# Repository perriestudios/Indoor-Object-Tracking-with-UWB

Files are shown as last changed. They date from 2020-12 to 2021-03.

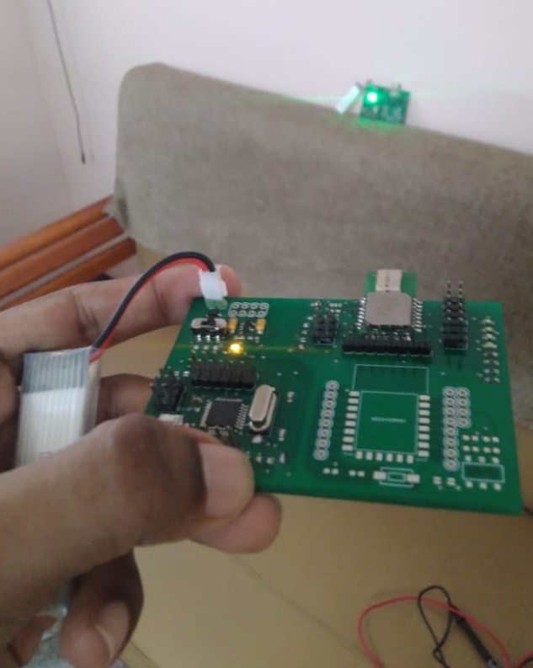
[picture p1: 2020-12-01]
Project Pictures/image15.jpeg

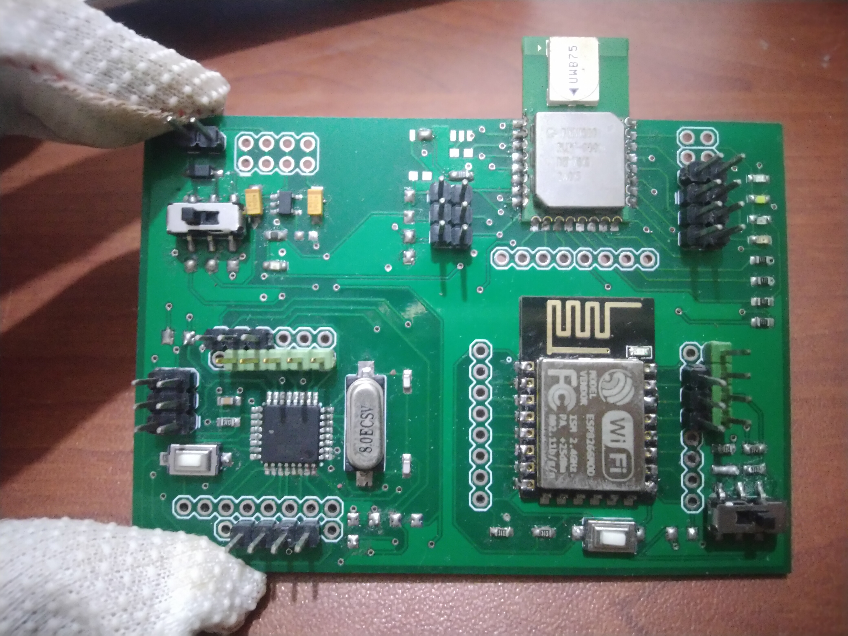
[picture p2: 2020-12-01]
Project Pictures/IMG_20201201_192204.jpg

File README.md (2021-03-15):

# <p align="center">Indoor-Object-Tracking-using-UWB </p>
## Introduction

<p align= "justify" > The objective of this project was to create an accurate general-purpose indoor localization system. Ultra-wideband(UWB) a wireless radio technology was chosen to achieve this. UWB offers high accuracy of localization, low latency, minimal interference and noise, and large bandwidth. DW1000 is an RF TX/RX IC manufactured by Decawave for UWB applications. This project uses the DW1000 IC in the form factor of module DWM1000. The hardware for the project was designed around this module with a few preferable features like access to the internet using an ESP8266-12E and programming support using the Arduino IDE. The system uses the Two-Way Ranging(TWR) technique for localization. The position computing is done by trilateration on the tag which is coupled with the object being tracked. A localization accuracy of about 12cm was achieved in a room of size 3x3m.</p>

## System Design

<p align="center">
  
</p>
<p align= "justify" > In order to track an object, a device addressed "Tag" is attached to it. Devices callled "Anchors" are placed around the indoor environment to provide a spatial reference for the tag. Before the system starts tracking, the anchors should be fixed at different locations in the room and their coordinates are programmed in the tag. As shown in the above block diagram, the anchors are placed at (x1,y1),(x2,y2) and (x3,y3) respectively. Calibration of the DWM1000 is then done to accomodate for the slight difference in the radiation pattern of each antenna as mentioned in the datasheet of the module.</p>

## Working

<p align= "justify" > Once the setup is ready, the tag performs Two-Way Ranging to determine its distance from each anchor. The three distances are then substituted into the trilateration formula to determine the exact position. This data may then be shared with an anchor with a Wi-Fi module called the master anchor. The master anchor can then update the data anywhere over the internet. In this project, a dynamic webpage hosted on the ESP8266 displays the coordinates of the object. This entire cycle is repeated to track the position of the tag(in turn the object) in real time. A flow chart of the process is shown below:</p>


## Hardware
### PCB: Version 1

<p align= "justify" > As stated in the introduction, the hardware was designed around the DWM1000 module. Since the module operates between 2.8-3.6v, the system voltage was fixed to be 3v3. This also provided the convinience of using a handy single cell 750mah lipo battery. ATmega328P was chosen as the microcontroller due to my familiarity with it. An external 8MHz crystal oscillator was connected to ensure the microcontroller is clocked at the fastest possible speed at 3v3. The minimal circuit required for ESP8266 was designed and interfaced with the ATmega328P over the I2C bus while the DWM1000 uses SPI. IC MIC5219 a low cost 500mA LDO was used to regulate the supply voltage to 3v3 from the battery. Additionally, reverse polarity protection using a diode is added. Switches were provided to control power and reset of ATmega328P and ESP8266, while LED's were provided to indicate the status of power and DWM1000.</p>



<p align= "justify" > The above PCB was designed in Autodesk Eagle. The design files can be found in the folder Master_V1 under the Hardware section of this repository. </p>

### PCB: Version 2

<p align= "justify" > The major feature of version 2 addition of programming over the USB. In the previous version, the bootloader was initally burned using an ATMEL ICE debugger and the program written over UART using an Arduino Uno performing USB-TTL conversion. However, I found it very inconvienient to interconnect the Uno everytime, reset it during programming and reading the data serially. Hence, the popular USB-TTL converter CH340G was added to support quicker programming and access to serial monitor. Pads were placed on the bottom to burn the bootloader using pogo pins. I also reduced the size of the crystals and switches to achieve the smallest possible form factor. </p>

<p align="center">

</p>

<p align= "justify" > The design files can be found under the Tag_V2 and Anchor_V2 folders respectively. The anchor design contains an additional ESP8266 placed in the bottom. </p>

### Enclosure

<p align="center">

</p>

<p align= "justify" > An enclosure was designed to house the device in Autodesk Fusion 360. The base was intended to be 3d printed on a PLA base which the lid will be a transparent laser cut acrylic. The PCB will be screwed on to the enclosure. The design file can be found under the hardware section</p>

## Software

<p align= "justify" > The firmware for the project was completely written in Arduino IDE with <a href="https://github.com/thotro/arduino-dw1000" target="_blank" rel="noopener noreferrer">arduino-dw1000 library</a> developed by Thomas Trojer. The programs could be found under the software section of this repository. </p>

## Working

<p align= "justify" > After uploading the program, the tag should be set in calibration mode to perform TWR and correct the calibration constant. After this, open a browser and navigate to the IP addess mentioned in the serial monitor of the master-anchor. The position of the tag will be updated every 10s in real-time with an accuracy < 30cm.</p>



## Outcome

<p align= "justify" >This capstone project was undertaken as part of my UG curriculum. Version 2 of the hardware did not progress beyond the design stage due to my graduation in May 2020, during the middle of the pandemic here. Fortunately, I was able to demonstate the working of the system using the first version of the hardware to earn my degree. However, as a hobby project, I am working on a TDoA implementation of the system to be deployed at Beeclust MRSL for tracking robots. It will be replacement for the april tags currently used in the projects. There are certain aspects of the system that could still be improved. Feel free to contact me if you would like to improve this project.</p>

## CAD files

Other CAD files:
Hardware/Enclosure_V2/Tag_v2.f3d

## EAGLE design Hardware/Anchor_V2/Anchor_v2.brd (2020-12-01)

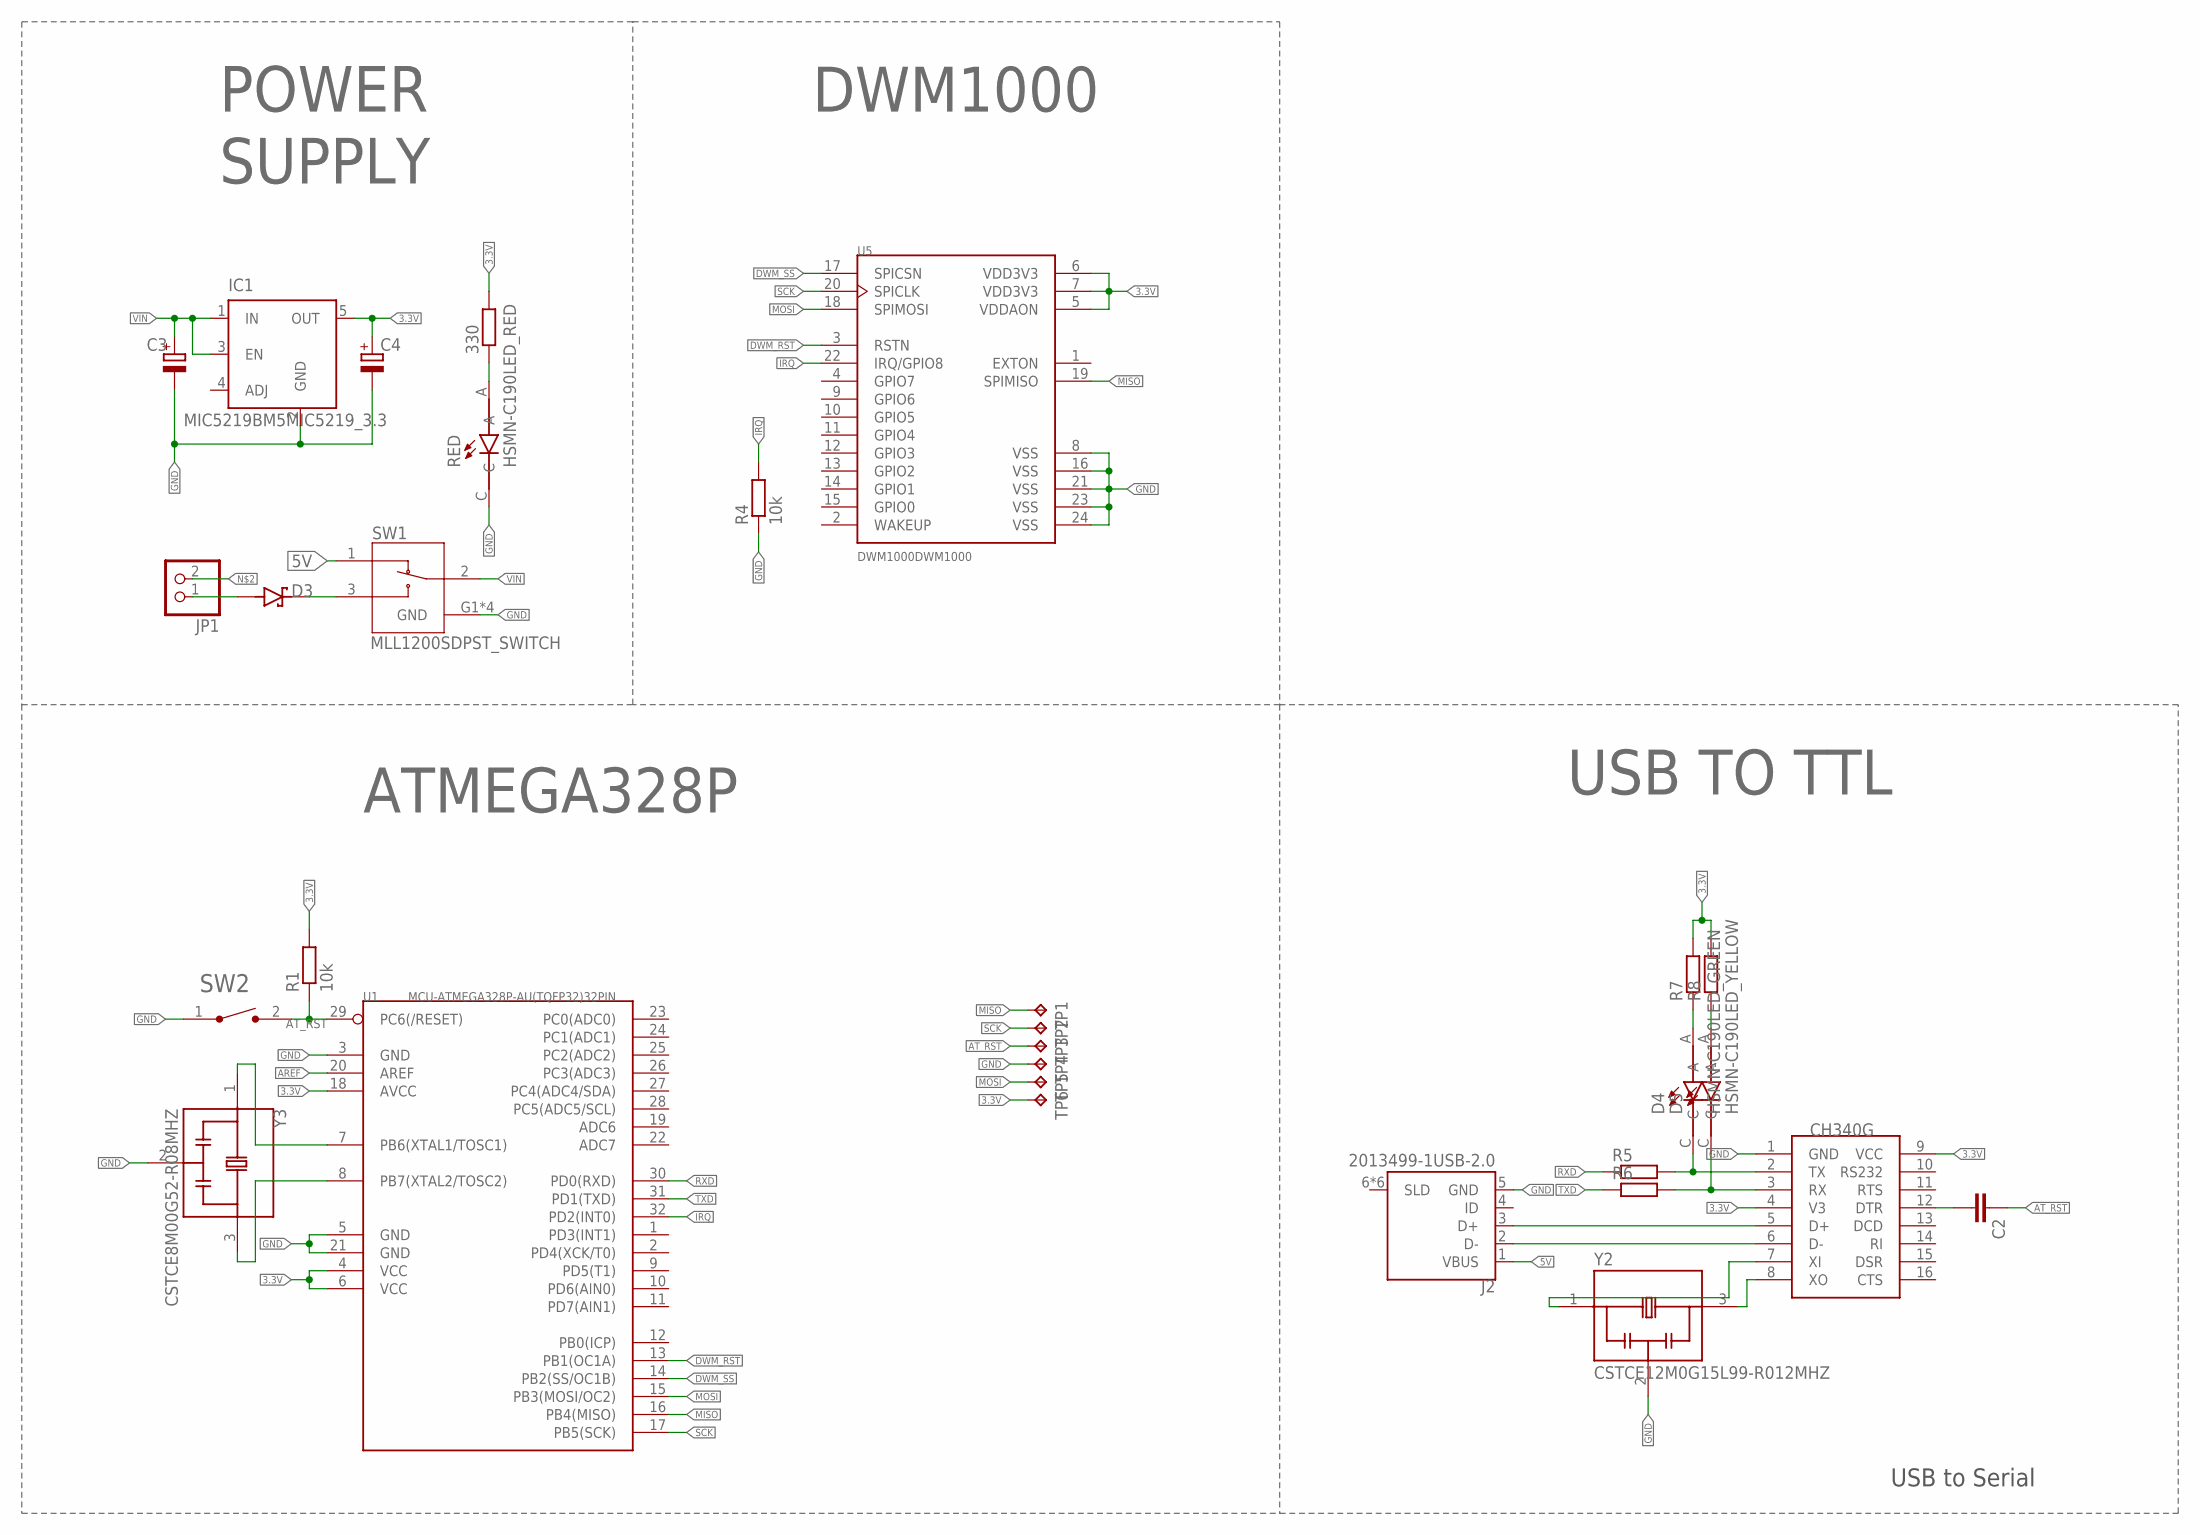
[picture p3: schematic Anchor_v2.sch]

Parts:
330: R-EU_R0603; R0603
C2: C-EUC0603; C0603
C3, C4: CPOL-EUA/3216-18R; A/3216-18R
D3: 1N5819HW-7-FSCHOTTKEYDIODE; SOD3715X145N_NEW
D4: HSMN-C190LED_GREEN; LEDM1608X80_NEW
D5: HSMN-C190LED_YELLOW; LEDM1608X80_NEW
IC1: MIC5219BM5MIC5219_3.3; SOT23-5_NEW
J2: 2013499-1USB-2.0; TE_2013499-1_NEW
JP1: PINHD-1X2; 1X02
R1, R4: 10k; R0603
R5, R6, R7, R8: R-EU_R0603; R0603
RED: HSMN-C190LED_RED; LEDM1608X80_NEW
SW1: MLL1200SDPST_SWITCH; SW_MLL1200S_NEW
SW2: FSMSMRESET_SPST; TE_FSMSM_NEW
TP1, TP2, TP3, TP4, TP5, TP6: TPB1,27; B1,27
U1: MCU-ATMEGA328P-AU(TQFP32)32PIN; TQFP32-0.8-7X7MM_NEW
U5: DWM1000DWM1000; XCVR_DWM1000_NEW
U$1: CH340G16PIN; SOIC16_NEW
Y2: CSTCE12M0G15L99-R012MHZ; OSC_CSTCE12M0G15L99-R0_NEW
Y3: CSTCE8M00G52-R08MHZ; OSC_CSTCE8M00G52-R0_NEW

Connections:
3.3V: 330.2, C4.+, IC1.5 (OUT), R1.2, R7.2, R8.2, TP6.TP, U1.4 (VCC), U1.6 (VCC), U1.18 (AVCC), U5.5 (VDDAON), U5.6 (VDD3V3), U5.7 (VDD3V3), U$1.4 (V3), U$1.9 (VCC)
5V: J2.1 (VBUS), SW1.1
AREF: U1.20 (AREF)
AT_RST: C2.1, R1.1, SW2.2, TP3.TP, U1.29 (PC6(/RESET))
DWM_RST: U1.13 (PB1(OC1A)), U5.3 (RSTN)
DWM_SS: U1.14 (PB2(SS/OC1B)), U5.17 (SPICSN)
GND: C3.-, C4.-, IC1.2 (GND), J2.5 (GND), R4.1, RED.C, SW1.G1 (GND), SW1.G2 (GND), SW1.G3 (GND), SW1.G4 (GND), SW2.1, TP4.TP, U1.3 (GND), U1.5 (GND), U1.21 (GND), U5.8 (VSS), U5.16 (VSS), U5.21 (VSS), U5.23 (VSS), U5.24 (VSS), U$1.1 (GND), Y2.2, Y3.2
IRQ: R4.2, U1.32 (PD2(INT0)), U5.22 (IRQ/GPIO8)
MISO: TP1.TP, U1.16 (PB4(MISO)), U5.19 (SPIMISO)
MOSI: TP5.TP, U1.15 (PB3(MOSI/OC2)), U5.18 (SPIMOSI)
unnamed: U1.7 (PB6(XTAL1/TOSC1)), Y3.1
unnamed: D3.A, JP1.1
unnamed: D3.C (K), SW1.3
unnamed: U1.8 (PB7(XTAL2/TOSC2)), Y3.3
unnamed: 330.1, RED.A
unnamed: D4.C, R5.2, U$1.2 (TX)
unnamed: C2.2, U$1.12 (DTR)
unnamed: U$1.8 (XO), Y2.3
unnamed: D5.C, R6.2, U$1.3 (RX)
unnamed: D4.A, R7.1
unnamed: D5.A, R8.1
unnamed: U$1.7 (XI), Y2.1
unnamed: J2.2 (D-), U$1.6 (D-)
unnamed: J2.3 (D+), U$1.5 (D+)
RXD: R5.1, U1.30 (PD0(RXD))
SCK: TP2.TP, U1.17 (PB5(SCK)), U5.20 (SPICLK)
TXD: R6.1, U1.31 (PD1(TXD))
VIN: C3.+, IC1.1 (IN), IC1.3 (EN), SW1.2

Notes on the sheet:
POWER
SUPPLY
USB to Serial
DWM1000
ATMEGA328P
USB TO TTL

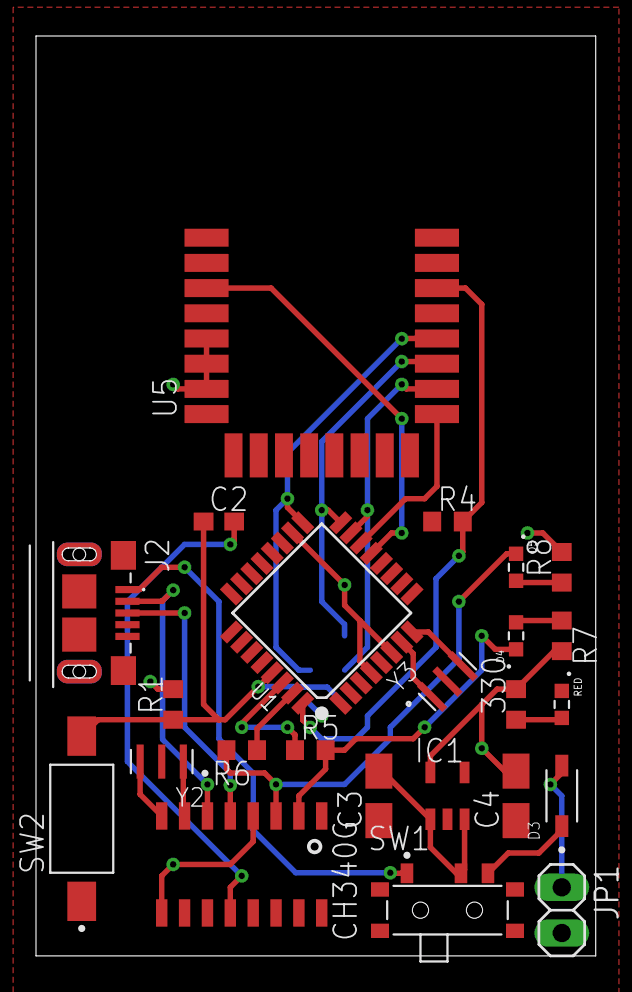
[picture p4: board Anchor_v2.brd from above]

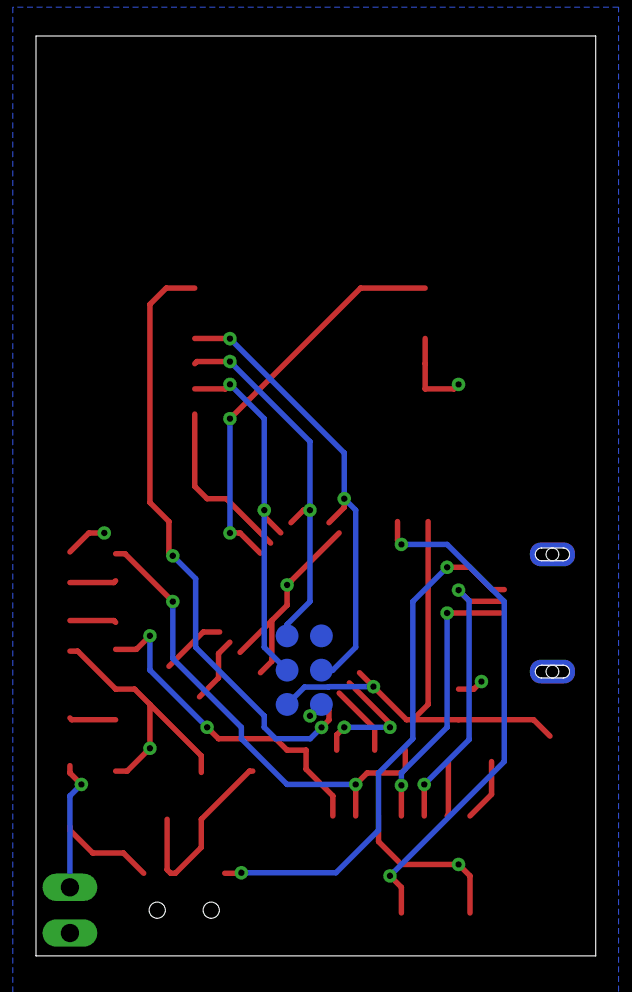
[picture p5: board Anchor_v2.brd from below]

Board: 2 copper layers, 31.1 x 51.1 mm, 30 parts (6 on the bottom side), 27 nets.

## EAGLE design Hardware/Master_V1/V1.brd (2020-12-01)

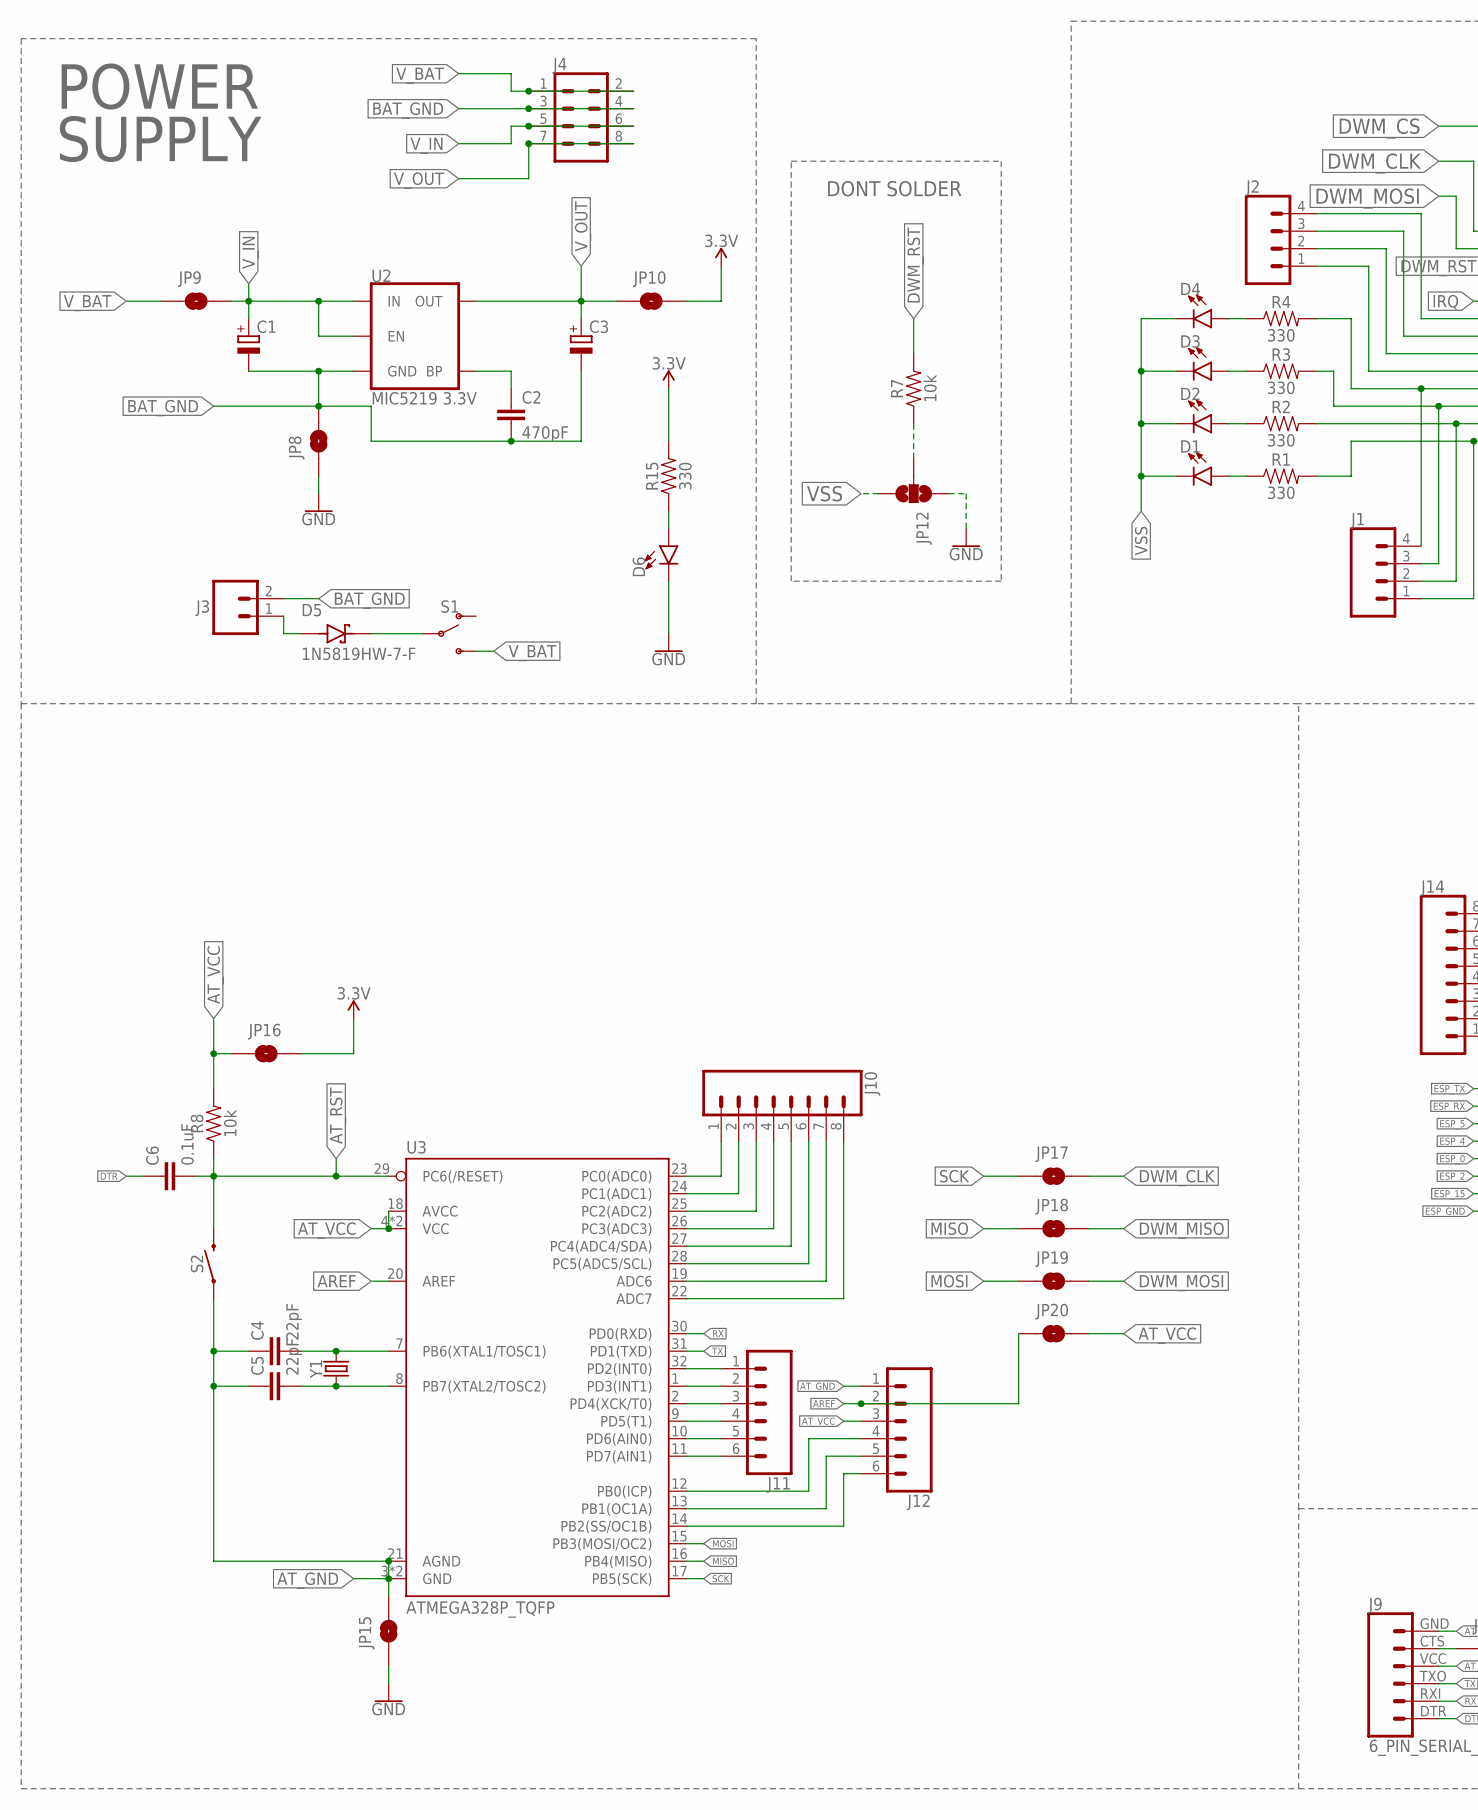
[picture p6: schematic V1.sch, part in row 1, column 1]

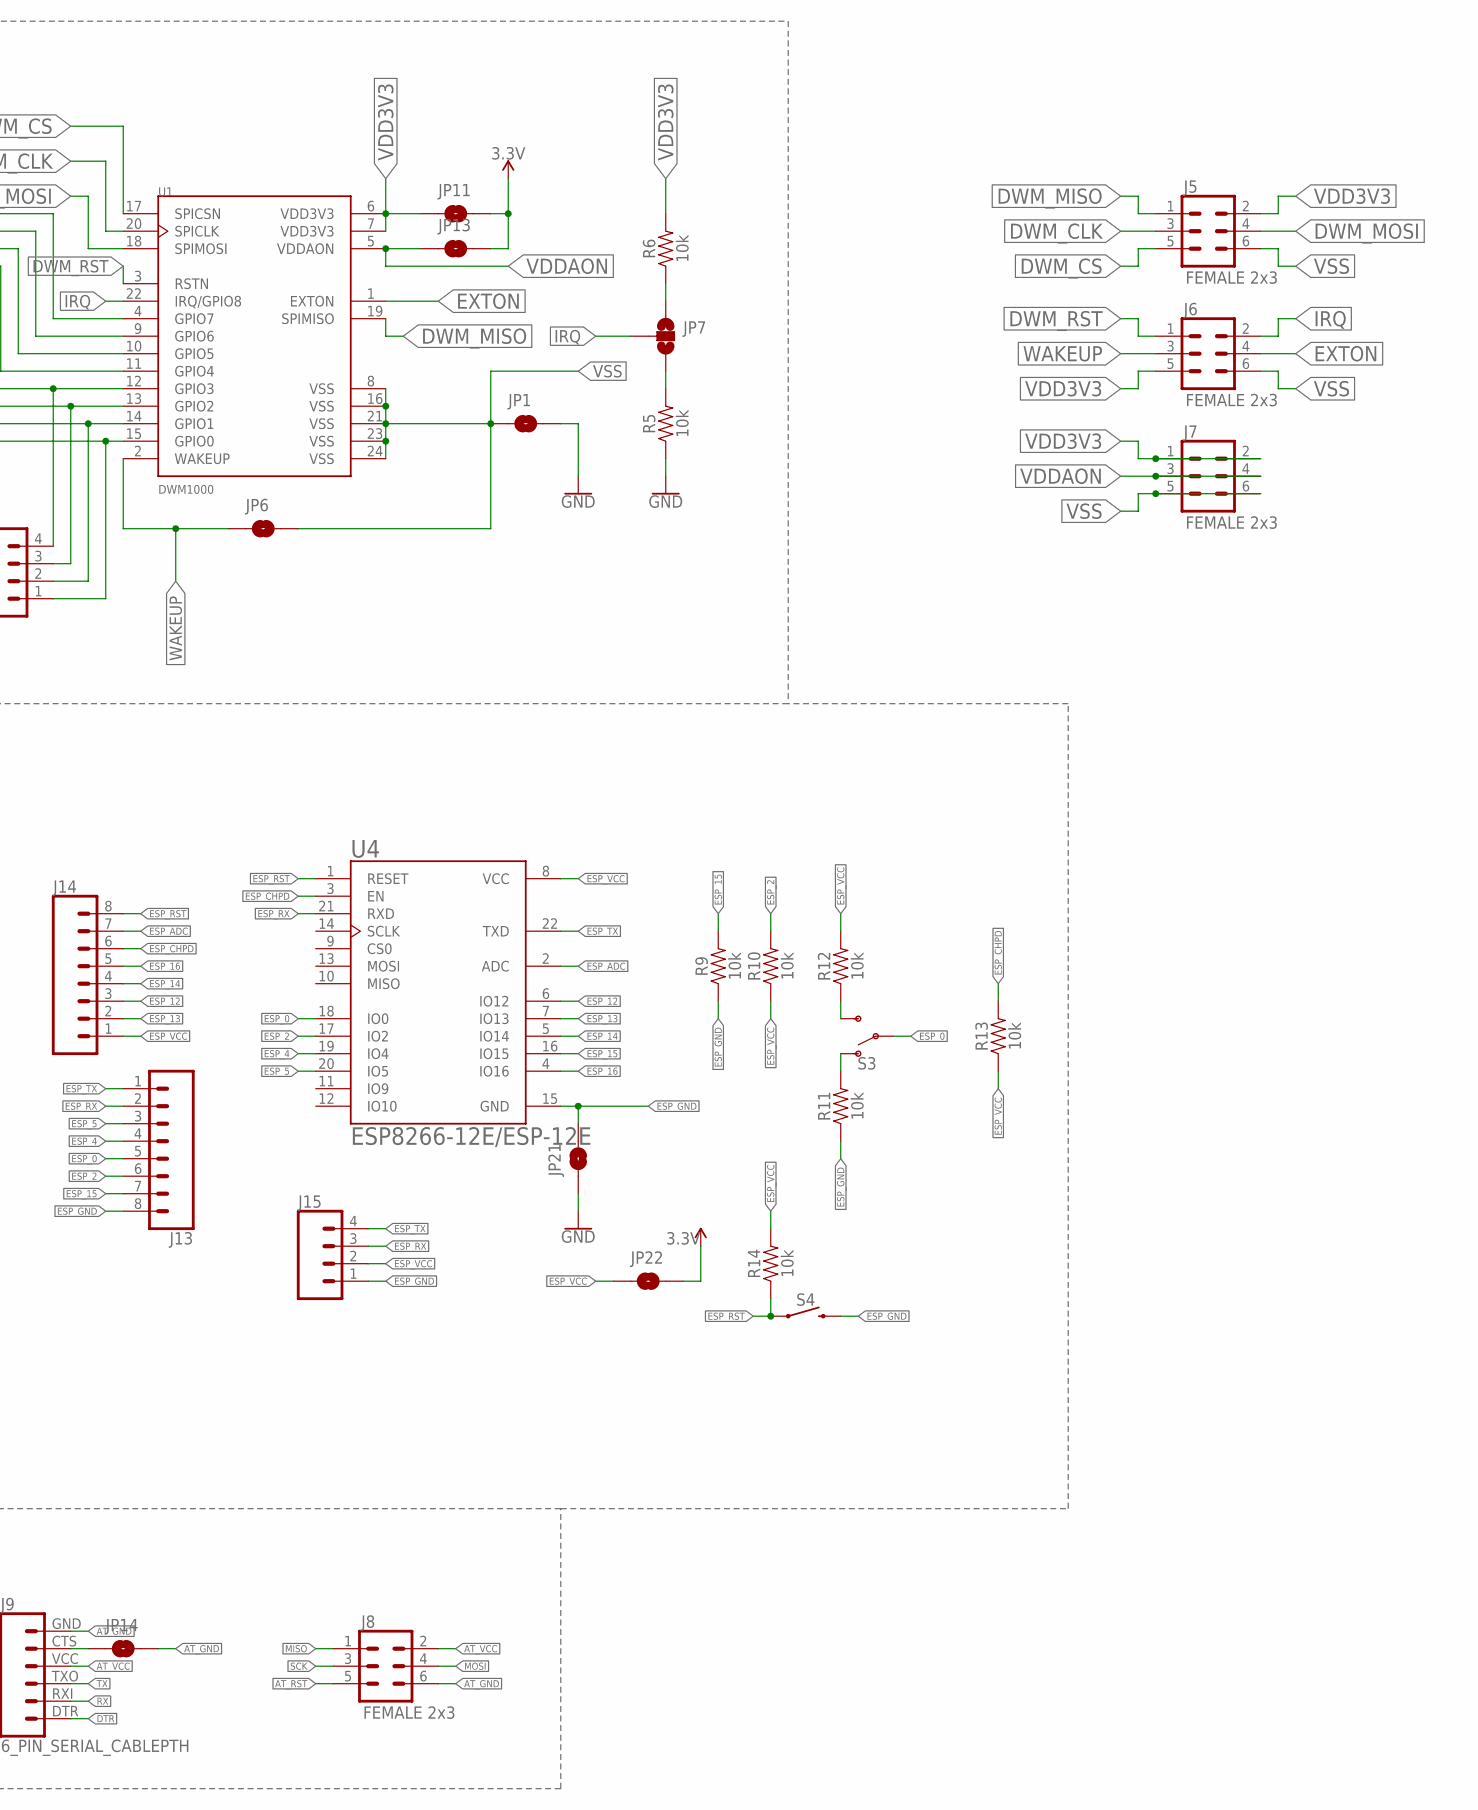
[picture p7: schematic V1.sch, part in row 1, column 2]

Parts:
C1, C3: CPOL-EUSMCA; SMC_A
C2: 470pF; 0603
C4, C5: 22pF; 0603
C6: 0.1uF; 0603
D1, D2, D3, D4, D6: LED0603; LED-0603
D5: 1N5819HW-7-F; SOD3715X145N
J1, J2, J15: CONN_04; 1X04
J3: CONN_02; 1X02
J4: CONN_04X2; 2X4
J5, J6, J7, J8: FEMALE 2x3; 2X3
J9: 6_PIN_SERIAL_CABLEPTH; FTDI_BASIC
J10, J13, J14: CONN_08"; 1X08
J11, J12: CONN_06SILK_FEMALE_PTH; 1X06
JP1, JP6, JP8, JP9, JP10, JP11, JP13, JP14, JP15, JP16, JP17, JP18, JP19, JP20, JP21, JP22: JUMPER-SMT_2_NO_NO-SILK; SMT-JUMPER_2_NO_NO-SILK
JP7, JP12: JUMPER-SMT_3_NO_NO_SILK; SMT-JUMPER_3_0-NO_TRACE_NO-SILK
R1, R2, R3, R4, R15: 330; 0603
R5, R6, R7, R8, R9, R10, R11, R12, R13, R14: 10k; 0603
S1, S3: SWITCH-SPDT-SMD-AYZ0202; SWITCH_DPDT_SMD_AYZ0202
S2, S4: MOMENTARY-SWITCH-SPST-SMD-6.0X3.5MM; TACTILE_SWITCH_SMD_6.0X3.5MM
U1: DWM1000; XCVR_DWM1000
U2: MIC5219 3.3V; SOT23-5
U3: ATMEGA328P_TQFP; TQFP32-08
U4: ESP8266-12E/ESP-12E; XCVR_ESP8266-12E/ESP-12E
Y1: CRYSTALSMD-HC49UP; HC49UP

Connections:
3.3V: JP10.2, JP11.2, JP13.2, JP16.2, JP22.2, R15.2
AREF: J12.2, JP20.1, U3.20 (AREF)
AT_GND: C4.1, C5.1, J8.6, J9.GND (6), J12.1, JP14.2, JP15.2, S2.1, U3.3 (GND), U3.5 (GND), U3.21 (AGND)
AT_RST: C6.2, J8.5, R8.1, S2.2, U3.29 (PC6(/RESET))
AT_VCC: J8.2, J9.VCC (4), J12.3, JP16.1, JP20.2, R8.2, U3.4 (VCC), U3.6 (VCC), U3.18 (AVCC)
BAT_GND: C1.-, C2.2, C3.-, J3.2, J4.3, J4.4, JP8.2, U2.2 (GND)
DTR: C6.1, J9.DTR (1)
DWM_CLK: J5.3, JP17.2, U1.20 (SPICLK)
DWM_CS: J5.5, U1.17 (SPICSN)
DWM_MISO: J5.1, JP18.2, U1.19 (SPIMISO)
DWM_MOSI: J5.4, JP19.2, U1.18 (SPIMOSI)
DWM_RST: J6.1, R7.2, U1.3 (RSTN)
ESP_0: J13.5, S3.2, U4.18 (IO0)
ESP_2: J13.6, R10.2, U4.17 (IO2)
ESP_4: J13.4, U4.19 (IO4)
ESP_5: J13.3, U4.20 (IO5)
ESP_12: J14.3, U4.6 (IO12)
ESP_13: J14.2, U4.7 (IO13)
ESP_14: J14.4, U4.5 (IO14)
ESP_15: J13.7, R9.2, U4.16 (IO15)
ESP_16: J14.5, U4.4 (IO16)
ESP_ADC: J14.7, U4.2 (ADC)
ESP_CHPD: J14.6, R13.2, U4.3 (EN)
ESP_GND: J13.8, J15.1, JP21.2, R9.1, R11.1, S4.2, U4.15 (GND)
ESP_RST: J14.8, R14.1, S4.1, U4.1 (RESET)
ESP_RX: J13.2, J15.3, U4.21 (RXD)
ESP_TX: J13.1, J15.4, U4.22 (TXD)
ESP_VCC: J14.1, J15.2, JP22.1, R10.1, R12.2, R13.1, R14.2, U4.8 (VCC)
EXTON: J6.4, U1.1 (EXTON)
GND: D6.C, JP1.2, JP8.1, JP12.1, JP15.1, JP21.1, R5.1
IN_BAT: D5.C (K), S1.2
IRQ: J6.2, JP7.2, U1.22 (IRQ/GPIO8)
MISO: J8.1, JP18.1, U3.16 (PB4(MISO))
MOSI: J8.4, JP19.1, U3.15 (PB3(MOSI/OC2))
unnamed: J1.4, R4.2, U1.12 (GPIO3)
unnamed: C2.1, U2.4 (BP)
unnamed: J1.3, R3.2, U1.13 (GPIO2)
unnamed: J1.2, R2.2, U1.14 (GPIO1)
unnamed: J1.1, R1.2, U1.15 (GPIO0)
unnamed: D4.A, R4.1
unnamed: D3.A, R3.1
unnamed: D2.A, R2.1
unnamed: D1.A, R1.1
unnamed: J2.1, U1.11 (GPIO4)
unnamed: JP7.1, R6.1
unnamed: J2.2, U1.10 (GPIO5)
unnamed: J2.3, U1.9 (GPIO6)
unnamed: J2.4, U1.4 (GPIO7)
unnamed: JP7.3, R5.2
unnamed: D5.A, J3.1
unnamed: C4.2, U3.7 (PB6(XTAL1/TOSC1)), Y1.2
unnamed: JP12.2, R7.1
unnamed: C5.2, U3.8 (PB7(XTAL2/TOSC2)), Y1.1
unnamed: J10.1, U3.23 (PC0(ADC0))
unnamed: J10.2, U3.24 (PC1(ADC1))
unnamed: J10.3, U3.25 (PC2(ADC2))
unnamed: J10.4, U3.26 (PC3(ADC3))
unnamed: J9.CTS (5), JP14.1
unnamed: J10.5, U3.27 (PC4(ADC4/SDA))
unnamed: J10.6, U3.28 (PC5(ADC5/SCL))
unnamed: J10.7, U3.19 (ADC6)
unnamed: J10.8, U3.22 (ADC7)
unnamed: J11.1, U3.32 (PD2(INT0))
unnamed: J11.2, U3.1 (PD3(INT1))
unnamed: J11.3, U3.2 (PD4(XCK/T0))
unnamed: J11.4, U3.9 (PD5(T1))
unnamed: J11.5, U3.10 (PD6(AIN0))
unnamed: J11.6, U3.11 (PD7(AIN1))
unnamed: J12.5, U3.13 (PB1(OC1A))
unnamed: J12.4, U3.12 (PB0(ICP))
unnamed: J12.6, U3.14 (PB2(SS/OC1B))
unnamed: R11.2, S3.1 (O)
unnamed: R12.1, S3.3 (S)
unnamed: D6.A, R15.1
RX: J9.RXI (2), U3.30 (PD0(RXD))
SCK: J8.3, JP17.1, U3.17 (PB5(SCK))
TX: J9.TXO (3), U3.31 (PD1(TXD))
VDD3V3: J5.2, J6.5, J7.1, J7.2, JP11.1, R6.2, U1.6 (VDD3V3), U1.7 (VDD3V3)
VDDAON: J7.3, J7.4, JP13.1, U1.5 (VDDAON)
VSS: D1.C, D2.C, D3.C, D4.C, J5.6, J6.6, J7.5, J7.6, JP1.1, JP6.2, JP12.3, U1.8 (VSS), U1.16 (VSS), U1.21 (VSS), U1.23 (VSS), U1.24 (VSS)
V_BAT: J4.1, J4.2, JP9.1, S1.3 (S)
V_IN: C1.+, J4.5, J4.6, JP9.2, U2.1 (IN), U2.3 (EN)
V_OUT: C3.+, J4.7, J4.8, JP10.1, U2.5 (OUT)
WAKEUP: J6.3, JP6.1, U1.2 (WAKEUP)

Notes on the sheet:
POWER
SUPPLY
DONT SOLDER

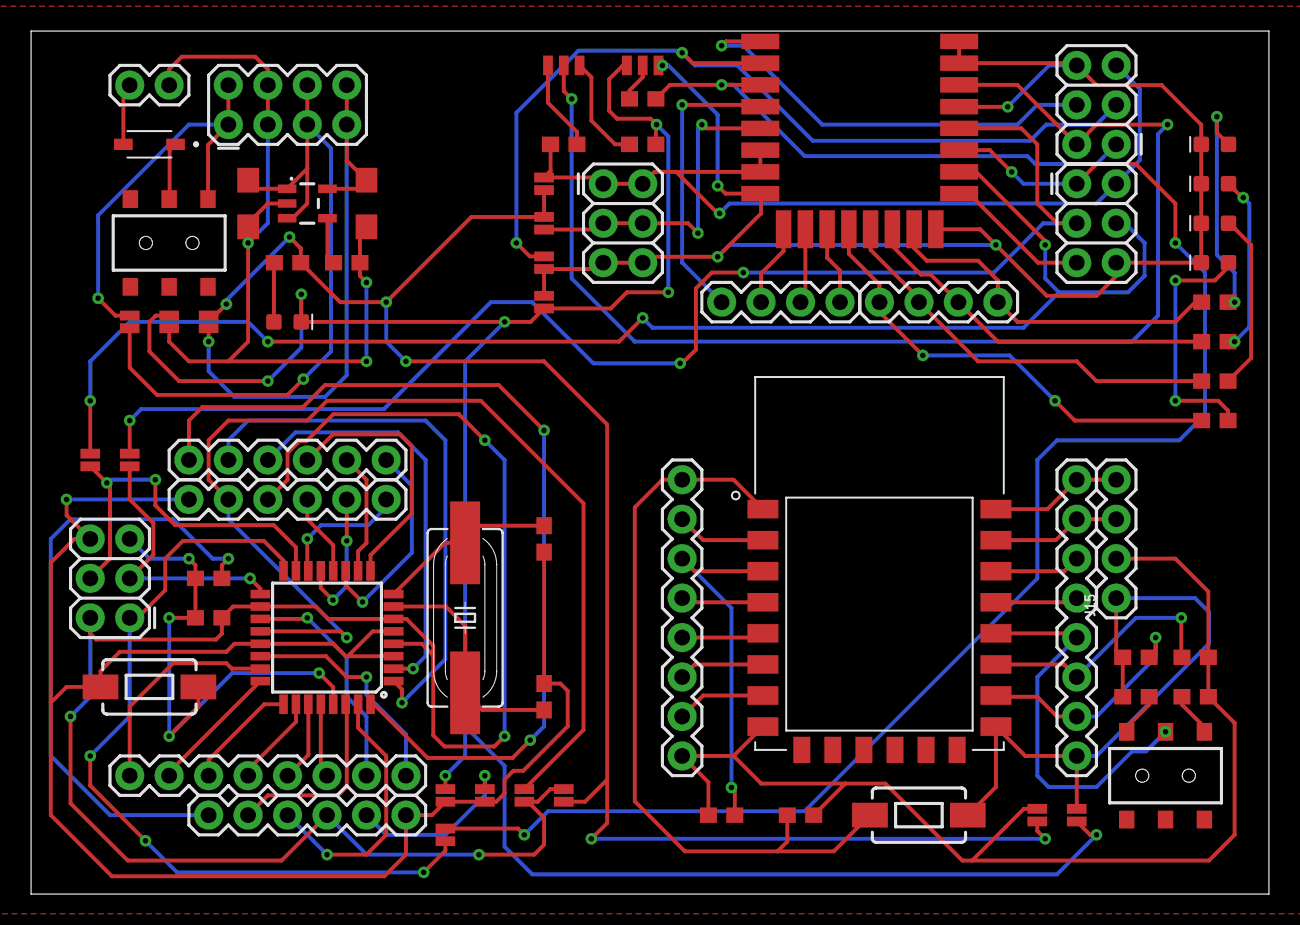
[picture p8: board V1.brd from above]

Board: 2 copper layers, 79.7 x 55.5 mm, 69 parts (0 on the bottom side), 84 nets.

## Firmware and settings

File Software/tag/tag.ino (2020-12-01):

#include <SPI.h>
#include "DW1000Ranging.h"
#include "DW1000Device.h"
#include <MatrixMath.h>
#include <math.h>

// If false, then use the calibration. If true, don't use the calibration.
#define CALIBRATE_FIRST false
#define CALIBRATE_SECOND false

//First distance from ground truth 2 meters
//Second from ground truth 5 meters.
#define BEACON_1_FIRSTDIST 1.368
#define BEACON_1_SECONDDIST 2.372

#define USE_MEDIAN_FILT true

#define BEACON_1_ADDRESS 0x1A1A
#define BEACON_2_ADDRESS 0x1A2A
#define BEACON_3_ADDRESS 0x1A3A

#define BEACON_1_X 0.00f
#define BEACON_1_Y 0.00f

#define BEACON_2_X 3.0f
#define BEACON_2_Y 0.0f

#define BEACON_3_X 0.0f
#define BEACON_3_Y 3.0f

//First distance from ground truth 2 meters
//Second from ground truth 5 meters.
#define BEACON_1_FIRSTDIST 1.368
#define BEACON_1_SECONDDIST 2.372
float beacon_1_slope = 1.0f/(BEACON_1_SECONDDIST-BEACON_1_FIRSTDIST);
float beacon_1_offset = 2.0f-(1.0f/beacon_1_slope*BEACON_1_SECONDDIST);

//First distance from ground truth 2 meters
//Second from ground truth 5 meters.
#define BEACON_2_FIRSTDIST 1.368
#define BEACON_2_SECONDDIST 2.372
float beacon_2_slope = 1.0f/(BEACON_2_SECONDDIST-BEACON_2_FIRSTDIST);
float beacon_2_offset = 2.0f-(1.0f/beacon_2_slope*BEACON_2_SECONDDIST);

//First distance from ground truth 2 meters
//Second from ground truth 5 meters.
#define BEACON_3_FIRSTDIST 1.368
#define BEACON_3_SECONDDIST 2.372
float beacon_3_slope = 1.0f/(BEACON_3_SECONDDIST-BEACON_3_FIRSTDIST);
float beacon_3_offset = 2.0f-(1.0f/beacon_3_slope*BEACON_3_SECONDDIST);
//
//#define BEACON_1_OFFSET 0.0368f
//#define BEACON_1_MULTIPLIER 1.0692f
//
//#define BEACON_2_OFFSET 0.6336f
//#define BEACON_2_MULTIPLIER 1.0440f
//
//#define BEACON_3_OFFSET 0.5575f
//#define BEACON_3_MULTIPLIER 1.0666f

// connection pins
const uint8_t PIN_RST = 9; // reset pin
const uint8_t PIN_IRQ = 2; // irq pin
const uint8_t PIN_SS = 10; // spi select pin
volatile unsigned long delaySent = 0;
volatile boolean sentAck = false;
volatile float range = 0;
volatile int address = 0;

volatile float dist[3] = {655.35, 655.35, 655.35};

float beacons[3][2] = {{BEACON_1_X, BEACON_1_Y},
                       {BEACON_2_X, BEACON_2_Y},
                       {BEACON_3_X, BEACON_3_Y}};

float shortestDistanceBeacon1 = 900.0f;
float shortestDistanceBeacon2 = 900.0f;
float shortestDistanceBeacon3 = 900.0f;

float A[3][3];

#define N (5)
struct cir {
    float a[N];
    unsigned h;
    unsigned t;
    unsigned n;
};
typedef volatile struct cir cir_t;

cir_t *cir_new() {
    cir_t *cir = malloc(sizeof(*cir));
    cir->h = 0;
    cir->t = N - 1;
    cir->n = N;
    return cir;
}


// if adding 1 to tail == head, then there is nothing
float cir_empty(cir_t *cir) {
    return (cir->t + 1) % N == cir->h;
}

// if adding 1 to head = tail, then we have no space.
float cir_full(cir_t *cir) {
    return cir->h == cir->t;
}

void cir_enqueue(cir_t *cir, float x) {
    if (cir_full(cir)) cir->t = (cir->t + 1) % N;
    cir->a[cir->h] = x;
    cir->h = (cir->h + 1) % N;
    
    // for(int i = 0; i < N; i++) {
    //     printf("%d ", cir->a[i]);
    // }
    // printf(": %d %d\n", cir->t, cir->h);
}


int compare(const void *x, const void * y) {
    float ix = *(float*)x;
    float iy = *(float*)y;
    return (int)(ix - iy);
}

float cir_median(cir_t *cir) {
    float q[cir->n];
    int qcount = 0;
    // Populate the array
    if(cir_empty(cir)) return 0;
    else if(cir_full(cir)) {
        qcount = cir->n;
        for(int i = 0; i < cir->n; i++) {
            q[i] = cir->a[i];
        }
    } else if(cir->t > cir->h) {
        for(int i = 0; i < cir->h; i++) {
            q[qcount] = cir->a[i];
            qcount++;
        }
        for(int i = cir->t; i < cir->n - 1; i++) {
            q[qcount] = cir->a[i];
            qcount++;
        }
    } else {
        for(int i = cir->t; i < cir->h; i++) {
            q[qcount] = cir->a[i];
            qcount++;
        }
    }
    // Sort the array
    qsort(q, qcount, sizeof(float), compare);
    
    // for(int i = 0; i < qcount; i++) {
    //     printf("%d ", q[i]);
    // }
    // printf("\n");
    
    return q[qcount/2];
}

cir_t *cir1 = cir_new();
cir_t *cir2 = cir_new();
cir_t *cir3 = cir_new();

void setup() {
  Serial.begin(115200);
  delay(1000);
  pinMode(6,OUTPUT);
  
  //init the configuration
  DW1000Ranging.initCommunication(PIN_RST, PIN_SS, PIN_IRQ);
  DW1000Ranging.attachNewRange(newRange);
  DW1000Ranging.startAsTag("7D:00:22:EA:82:60:3B:9C", DW1000.MODE_LONGDATA_RANGE_ACCURACY);
  //DW1000Ranging.useRangeFilter(true);
  unsigned long start, step_start, finished;

  start = micros();
  
  for(int i = 0; i < 3; i++) {
    A[i][0] = -2.0f*beacons[i][0];
    A[i][1] = -2.0f*beacons[i][1];
    A[i][2] = 1.0f;
  }

  Matrix.Invert((float*)A, 3);

  step_start = micros();

  Serial.println(step_start - start);
}
void loop() {
  DW1000Ranging.loop();
}

void newRange() {
    
  address = DW1000Ranging.getDistantDevice()->getShortAddress();

  range = DW1000Ranging.getDistantDevice()->getRange();
  if(range < 0) address = NULL;
  if(address == BEACON_1_ADDRESS){
    range *= CALIBRATE_FIRST||CALIBRATE_SECOND?1.0f:beacon_1_slope;
    range -= CALIBRATE_FIRST||CALIBRATE_SECOND?0.0f:beacon_1_offset;
    
    cir_enqueue(cir1,range);
    dist[0] = (USE_MEDIAN_FILT)?cir_median(cir1):range;
    
    if(CALIBRATE_FIRST||CALIBRATE_SECOND){
      if(dist[0] < shortestDistanceBeacon1 && dist[0] > 0){
        shortestDistanceBeacon1 = dist[0];
      }
    }
  }
  else if(address == BEACON_2_ADDRESS){
    range *= CALIBRATE_FIRST||CALIBRATE_SECOND?1.0f:beacon_2_slope;
    range -= CALIBRATE_FIRST||CALIBRATE_SECOND?0.0f:beacon_2_offset;
    cir_enqueue(cir2,range);
    dist[1] = (USE_MEDIAN_FILT)?cir_median(cir2):range;
    
    if(CALIBRATE_FIRST||CALIBRATE_SECOND){
      if(dist[1] < shortestDistanceBeacon2 && dist[1] > 0){
        shortestDistanceBeacon2 = dist[1];
      }
    }
  }
  else if(address == BEACON_3_ADDRESS){
    range *= CALIBRATE_FIRST||CALIBRATE_SECOND?1.0f:beacon_3_slope;
    range -= CALIBRATE_FIRST||CALIBRATE_SECOND?0.0f:beacon_3_offset;
    cir_enqueue(cir3,range);
    dist[2] = (USE_MEDIAN_FILT)?cir_median(cir3):range;
    
    if(CALIBRATE_FIRST||CALIBRATE_SECOND){
      if(dist[2] < shortestDistanceBeacon3 && dist[2] > 0){
        shortestDistanceBeacon3 = dist[2];
      }
    }
  }
  Serial.print("1: ");Serial.print(dist[0]);Serial.print(" 2: ");Serial.print(dist[1]);Serial.print(" 3: ");Serial.print(dist[2]);
  
  // ITERATIVE STEPS BELOW

  float y[3];
  for(int i = 0; i < 3; i++) {
    y[i] = float((dist[i])*(dist[i]) - (beacons[i][0])*(beacons[i][0]) - (beacons[i][1])*(beacons[i][1]));
  }
  float x[3];
  Matrix.Multiply((float*)A, (float*)y, 3, 3, 1, (float*)x);

  float estimate[2] = {x[0], x[1]};

  Serial.print(" Location: ["); Serial.print(estimate[0]); Serial.print("m, "); Serial.print(estimate[1]); Serial.print("m] \n");
  
  if(estimate[0] > 4.0f){
    digitalWrite(6,HIGH);
  }
  else digitalWrite(6,LOW);

  DW1000Ranging.setLoc(estimate[0], estimate[1]);
}

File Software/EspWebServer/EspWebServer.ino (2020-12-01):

#include <ESP8266WiFi.h>
#include <Wire.h>

// Replace with your network credentials
const char* ssid     = "pranav";
const char* password = "pranav123";

// Set web server port number to 80
WiFiServer server(80);

// Variable to store the HTTP request
String header;

// Current time
unsigned long currentTime = millis();
// Previous time
unsigned long previousTime = 0; 
// Define timeout time in milliseconds (example: 2000ms = 2s)
const long timeoutTime = 2000;

float x = 0;
float y = 0;

void setup() {
  Serial.begin(115200);
  Wire.begin(5, 4);
  // Connect to Wi-Fi network with SSID and password
  Serial.print("Connecting to ");
  Serial.println(ssid);
  WiFi.begin(ssid, password);
  while (WiFi.status() != WL_CONNECTED) {
    delay(500);
    Serial.print(".");
  }
  // Print local IP address and start web server
  Serial.println("");
  Serial.println("WiFi connected.");
  Serial.println("IP address: ");
  Serial.println(WiFi.localIP());
  server.begin();
}

void loop(){
  char d[9];
  int n = 0;
  Wire.requestFrom(8, 9); /* request & read data of size 13 from slave */
  while(Wire.available()){
  // char p = Wire.read();
   d[n] = 0;
   d[n] = Wire.read();
   n = n+1;
   if (n == 9){
    n = 0;
   }
   /*for (int j = 0; j <9; j++)
   {
    Serial.print(d[j]);
   } */
   //Serial.print(p);
  }
  Serial.println();
  delay(1000);

  /*int x_unit = c[0];
  int x_ten = c[2];
  int x_hund = c[3];
  int y_unit = c[5];
  int y_ten = c[7];
  int y_hund = c[8]; */
  float find_x = 0;
  find_x = d[0] + (0.1*d[2]) + (0.01*d[3]);
  find_x = find_x - 53.28;
  float find_y = 0;
  find_y = d[5] + (0.1*d[7]) + (0.01*d[8]);
  find_y = find_y - 53.28;
  //Serial.println(find_x);
  //Serial.println(find_y);
   
  WiFiClient client = server.available();   // Listen for incoming clients

  if (client) {                             // If a new client connects,
    Serial.println("New Client.");          // print a message out in the serial port
    String currentLine = "";                // make a String to hold incoming data from the client
    currentTime = millis();
    previousTime = currentTime;
    while (client.connected() && currentTime - previousTime <= timeoutTime) { // loop while the client's connected
      currentTime = millis();         
      if (client.available()) {             // if there's bytes to read from the client,
        char c = client.read();             // read a byte, then
        Serial.write(c);                    // print it out the serial monitor
        header += c;
        if (c == '\n') {                    // if the byte is a newline character
          // if the current line is blank, you got two newline characters in a row.
          // that's the end of the client HTTP request, so send a response:
          if (currentLine.length() == 0) {
            // HTTP headers always start with a response code (e.g. HTTP/1.1 200 OK)
            // and a content-type so the client knows what's coming, then a blank line:
            client.println("HTTP/1.1 200 OK");
            client.println("Content-type:text/html");
            client.println("Connection: close");
            client.println();
            
            // Display the HTML web page
            client.println("<!DOCTYPE html><html>");
            client.println("<head><meta name=\"viewport\" content=\"width=device-width, initial-scale=1\">");
            client.println("<link rel=\"icon\" href=\"data:,\">");
            // CSS to style the on/off buttons 
            // Feel free to change the background-color and font-size attributes to fit your preferences
            client.println("<style>html { font-family: Helvetica; display: inline-block; margin: 0px auto; text-align: center;}");
            client.println(".button { background-color: #195B6A; border: none; color: white; padding: 16px 40px;");
            client.println("text-decoration: none; font-size: 30px; margin: 2px; cursor: pointer;}");
            client.println(".button2 {background-color: #77878A;}</style></head>");
            
            // Web Page Heading
            client.println("<body><h1>Indoor Object Tracking using Ultra Wideband Localization</h1>");
            //x = x+5;
            //y = y+5;
            // Display current state, and ON/OFF buttons for GPIO 5  
            client.println(" X Co-ordinate:" + String(find_x) + "<br>");
            client.println(" Y Co-ordinate:" + String(find_y));
            client.println("<meta http-equiv=\"refresh\" content=\"1\">");
            client.println("</body></html>");
            
            // The HTTP response ends with another blank line
            client.println();
            // Break out of the while loop
            break;
          } else { // if you got a newline, then clear currentLine
            currentLine = "";
          }
        } else if (c != '\r') {  // if you got anything else but a carriage return character,
          currentLine += c;      // add it to the end of the currentLine
        }
      }
    }
    // Clear the header variable
    header = "";
    // Close the connection
    client.stop();
    Serial.println("Client disconnected.");
    Serial.println("");
  }
}

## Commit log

2020-12-01 Initial Push
    [Anchor_v1.brd, Anchor_v1.sch, Tag_v1.brd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]
2021-03-15 Sorted Name Discrepancy
    [Anchor_v2.brd, Anchor_v2.sch, Tag_v2.brd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]
2021-03-15 Added Fusion360 Mechanical Design
    [Tag_v2.f3d]
2021-03-15 Corrected name discrepancy in Software
    [EspWebServer.ino, anchor.ino, master-anchor.ino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]

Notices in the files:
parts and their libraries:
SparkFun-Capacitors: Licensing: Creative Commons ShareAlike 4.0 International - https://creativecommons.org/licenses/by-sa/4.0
